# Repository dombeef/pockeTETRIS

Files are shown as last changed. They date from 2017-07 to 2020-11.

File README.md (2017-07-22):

# pockeTETRIS
This project originally was meant as a fathers day gift for my tetris-loving father, and I felt like it should be available for others if they want to make a pretty small tetris clone. This was the smallest I could make it with a big enough battery and a thick durable 3d printed housing.

I modified tetris code created by Andy Jackson to be used with 3 buttons, since his original code was made for the AttinyArcade platform that has 2 buttons.

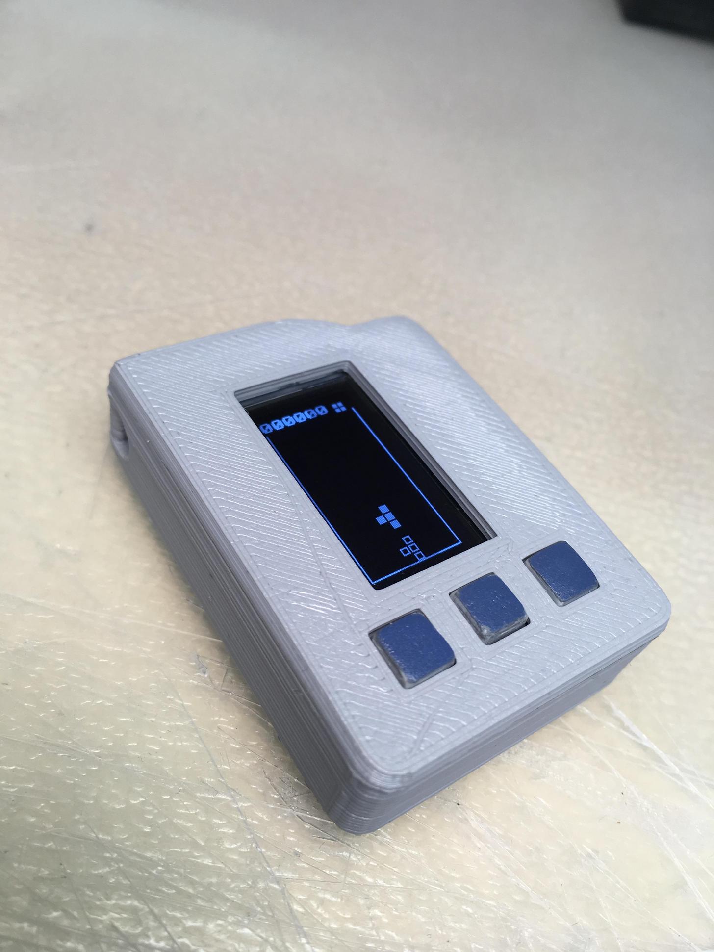
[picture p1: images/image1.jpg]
Final product


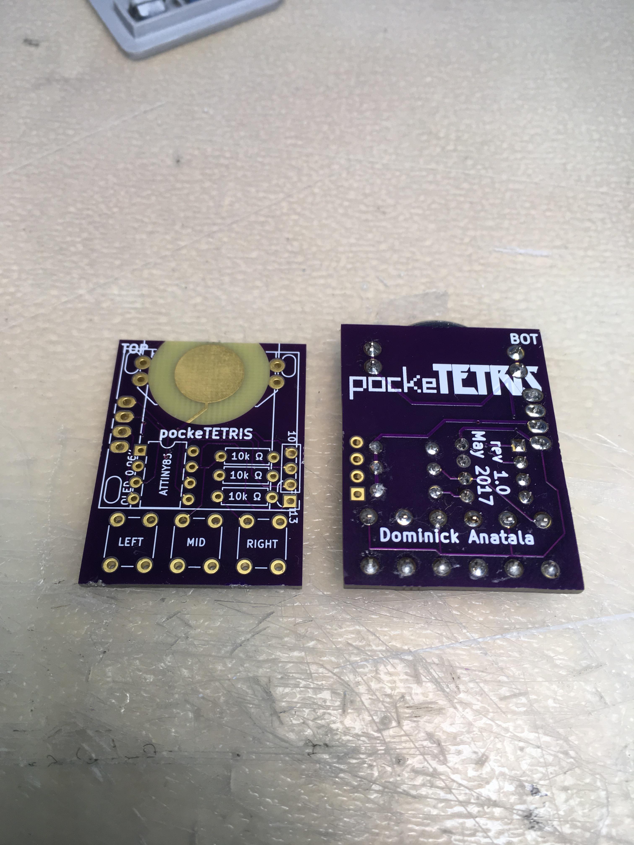
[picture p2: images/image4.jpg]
hand designed PCB with custom logo


### BOM
| Part  | Part number/ place to buy|
| --- | --- |
| Attiny85 | ATTINY85-20PU |
| CR2032 | CR2032 |
| Coin cell holder | BAT-HLD-001-THM|
| PCB from OSH Park | https://oshpark.com/shared_projects/mLy9Mwcr |
| 3d printed case | STL's available in the catia subfolder |
| buttons | [6x6x5 mm Push Button](https://www.amazon.com/CO-RODE-Tact-Button-Switch-6x6x5mm/dp/B00W0YUV1W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) |
| OLED 0.96' | [DIYmall 0.96" OLED](https://www.amazon.com/Diymall-Serial-128x64-Display-Arduino/dp/B01HHOETIA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) |
| 10 k Resistors | 1/4 Watt 10k ohm Resistors |

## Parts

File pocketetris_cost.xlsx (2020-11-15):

items | quantity | quantity needed | cost total | cost per unit | units possible | extra
Attiny85 | 5 | 1 | 10.98 | 2.196 | 5 | https://www.amazon.com/Original-Atmel-Dip-8-ATTINY85-20PU-Tiny85-20Pu/dp/B06W9JBJJ6?s=industrial
CR2032 | 4 | 1 | 2.68 | 0.67 | 4 | https://www.amazon.com/Energizer-2032BP-4-Volt-Lithium-Battery/dp/B00D8P5T0U?s=hpc
Coin cell holder | 10 | 1 | 2.8 | 0.28 | 10
pcb | 3 | 1 | 8.95 | 2.983333333 | 3
3d printed case | 1 | 1 | 0 | 0 | 1
buttons | 100 | 3 | 6.8 | 0.068 | 33.33333333 | https://www.amazon.com/CO-RODE-Tact-Button-Switch-6x6x5mm/dp/B00W0YUV1W
OLED 0.96' | 2 | 1 | 14.99 | 7.495 | 2 | https://www.amazon.com/Diymall-Serial-128x64-Display-Arduino/dp/B01HHOETIA
Resistors | 3 | 3 | 0 | 0 | 1
 |  | Total: | 47.2 | 13.69233333
through better bulk stuff
items | quantity | quantity needed | cost total | cost per unit | units possible
Attiny85 | 1 | 1 | 1.2 | 1.2 | 1 | https://www.digikey.com/en/products/detail/microchip-technology/ATTINY85-20PU/735469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
CR2032 | 1 | 1 | 0.33 | 0.33 | 1 | https://www.digikey.com/en/products/detail/zeus-battery-products/CR2032/9828855
Coin cell holder | 500 | 1 | 60 | 0.12 | 500 | https://www.alibaba.com/product-detail/Coin-Cell-Retainer-CR2032-2032-2020_62430101585.html
pcb | 10 | 1 | 5 | 0.5 | 10 | pcbway
3d printed case | 1 | 1 | 0 | 0 | 1
buttons | 20 | 1 | 0.5 | 0.025 | 20
OLED 0.96' | 10 | 1 | 18.6 | 1.86 | 10 | https://www.aliexpress.com/item/32717542815.html
Resistors | 3 | 3 | 0 | 0 | 1
 |  | Total: | 85.63 | 4.035

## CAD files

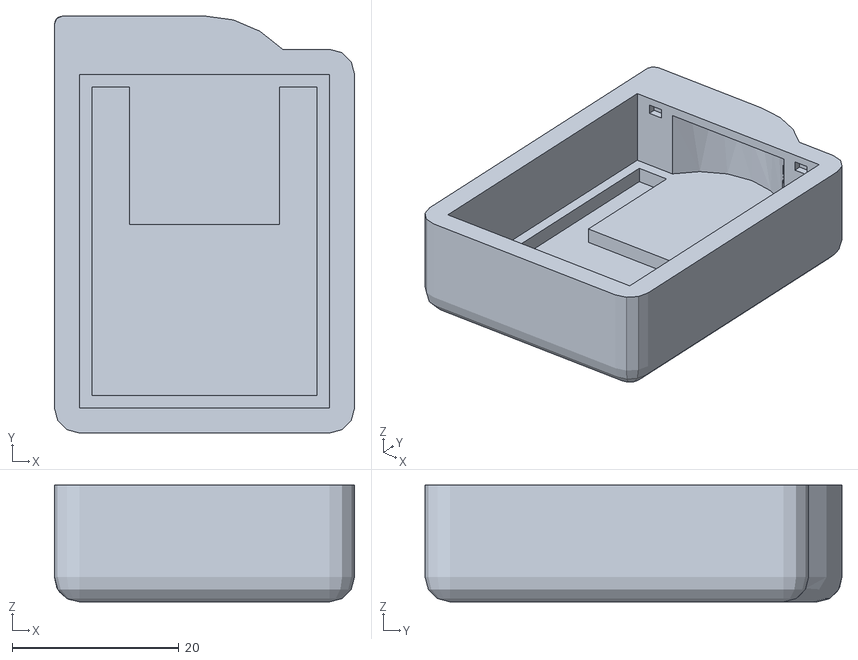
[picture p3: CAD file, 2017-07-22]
pockeTETRIS_catia/tetris_case_bottom.stl
36.0 x 50.0 x 14.0

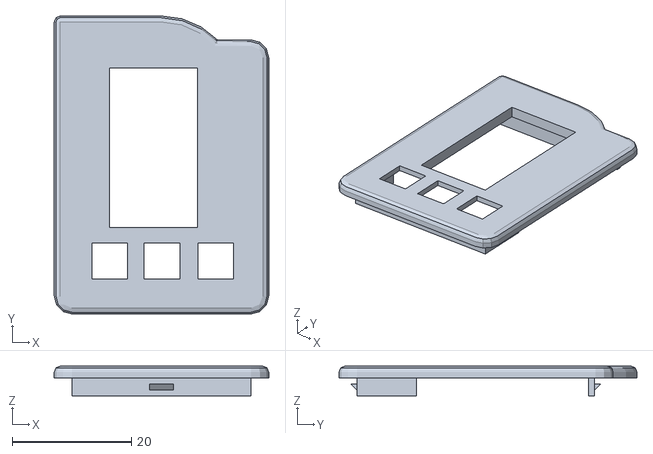
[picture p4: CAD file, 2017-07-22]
pockeTETRIS_catia/tetris_case_top.stl
36.0 x 50.0 x 5.00

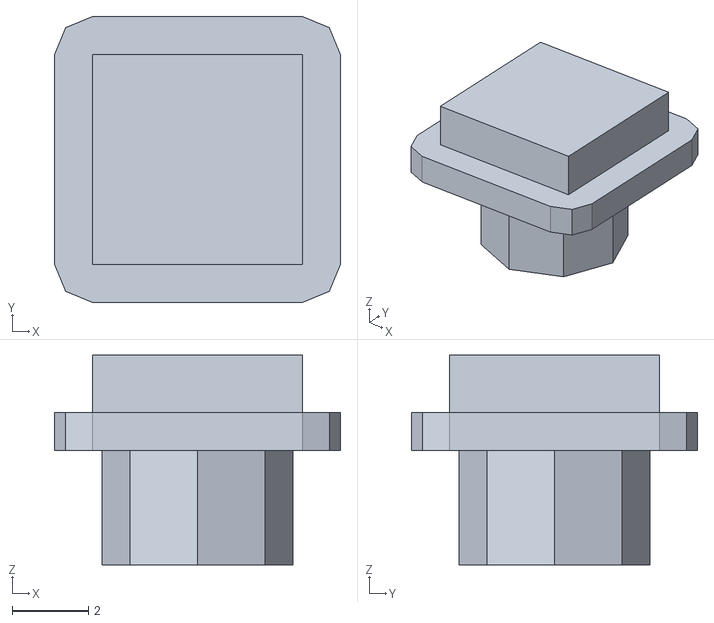
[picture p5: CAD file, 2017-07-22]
pockeTETRIS_catia/tetris_case_button_flush.stl
7.50 x 7.50 x 5.50

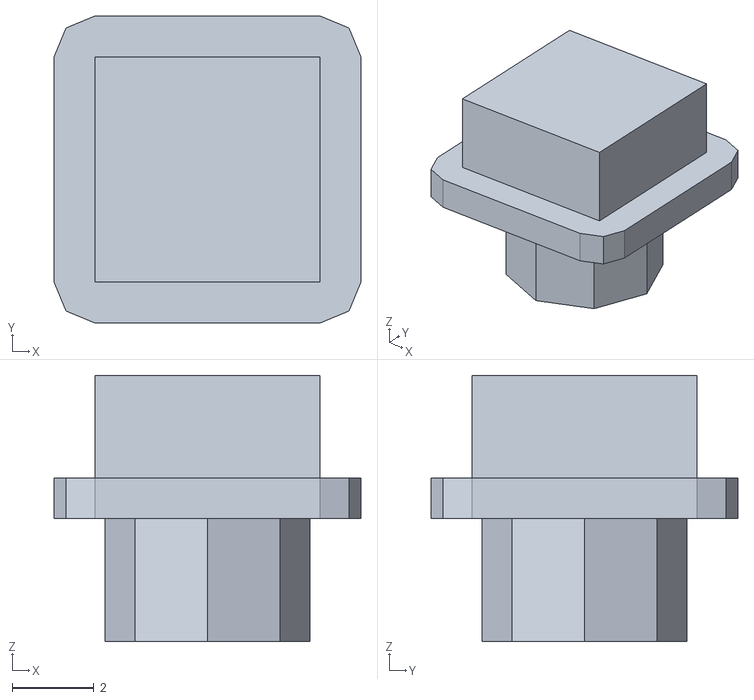
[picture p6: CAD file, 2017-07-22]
pockeTETRIS_catia/tetris_case_button.stl
7.50 x 7.50 x 6.50

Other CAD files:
pockeTETRIS_catia/tetris_assembly.CATProduct
pockeTETRIS_catia/tetris_case_bottom.CATPart
pockeTETRIS_catia/tetris_case_button.CATPart
pockeTETRIS_catia/tetris_case_button_flush.CATPart
pockeTETRIS_catia/tetris_case_top.CATPart

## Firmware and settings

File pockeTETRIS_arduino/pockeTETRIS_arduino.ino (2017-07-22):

/* 2015 / 2016 /2017

    Dominick Anatala
    modified for 3 buttons, removed wrapping around edges since we now have 3 buttons
        

   Tetris for Attiny Arcade
   ========================

   When the game is running :
   ==========================
   
   Tap LEFT BUTTON - Moves the piece to the left (and wraps around at the left edge)
   Hold LEFT BUTTON - Move the piece to the right
   Tap RIGHT BUTTON - Rotates the piece
   Hold RIGHT BUTTON - Place the piece

   Before the game starts:
   =======================
   Hold LEFT BUTTON - Turns 'ghost' piece on and off
   Hold MIDDLE and LEFT BUTTONS together - Turns 'challenge mode' on and off (which fills the screens with random stuff at the start of the game to make
   it more tricky!)


   _______________________________________________
   __________________________________________________________________________________________________________
   This version developed by Andy Jackson - Twitter @andyhighnumber - Tweet me if you have any problems getting this to compile or run.
   The code that does not fall under
   the licenses of sources listed below can be used non-commercially with or without attribution.
   This software is supplied without warranty of any kind.

   Designed for the Attiny85 and optimised for the #AttinyArcade platform. The source code is less than 8KB and the sketch
   should run happily with less than 300 bytes of RAM. You can find out more about this platform from http://webboggles.com/, buy kits
   to make it (or get instructions / schematics). This sketch includes some code from the #AttinyArcade games on that site, including interrupt code.

   This game started life as a port but is now essentially a clone of TinyTetris by Anthony Russell, with some additional features. There remain
   elements of that original codebase, although the vast majority of what's here has been rewritten from scratch (including the screen, text and number
   rendering code and much of the game engine) in order to optimise for memory, improve responsiveness and allow new features on the limited hardware
   (added features include Highscore (saved to EEPROM), optional Ghost (or Shadow) Piece, Interrupt Handling and Hard-Mode functionality).

   Anthony's source can be found here: https://github.com/AJRussell/Tiny-Tetris and is highly recommended if you'd like a version
   of Tetris to run on normal Arduino hardware. It has some lovely graphics by Tobozo (one image from which is now inclded the opening screen here!) and it's
   also possible that some code by Tobozo has made it into this version. Tobozo's repository can be found here; https://github.com/tobozo and is well worth a look.
   There is an In]]]
   structables page relating to this project here: https://www.instructables.com/id/Tetris-Clone-With-OLED-SSD1306I2C-for-Arduino-Nano/

   This sketch is using the screen control and font functions written by Neven Boyanov for the http://tinusaur.wordpress.com/ project
   Source code and font files available at: https://bitbucket.org/tinusaur/ssd1306xled - hacked about by Andy Jackson to make them
   render side-on for this game. All the necessary functions are in this file, there's no need to download any additional libraries to compile this game.

   The sleep code in this file is based on this blog post by Matthew Little:
   http://www.re-innovation.co.uk/web12/index.php/en/blog-75/306-sleep-modes-on-attiny85
*/

// The custom font file is the only additional file you should need to compile this game
#include "font8x8AJ.h"

// Standard Arduino headers
#include <EEPROM.h>
#include <avr/pgmspace.h>
#include <avr/sleep.h>
#include <avr/interrupt.h> // needed for the additional interrupt

// Mode settings for functions with multiple purposes
#define NORMAL 0
#define GHOST 1
#define FULL 0
#define PARTIAL 1
#define DRAW 0
#define ERASE 1

// The horizontal width of the playing area
#define HORIZ 10
// The vertical visible space of the playing area
#define VERTDRAW 19
// The size of the array of blocks (some are outside visible area to allow them to drop in from off screen)
#define VERTMAX 24

// The horizontal position where pieces begin
#define STARTX 3
// The vertical position where pieces begin
#define STARTY 19
// What level does the game start on
#define STARTLEVEL 1
// The multiplying factor that sets how the speed scales with level (one level increment for every row cleared)
#define LEVELFACTOR 4
// The number of milliseconds before each drop (baseline)
#define DROPDELAY 600

#define DIGITAL_WRITE_HIGH(PORT) PORTB |= (1 << PORT)
#define DIGITAL_WRITE_LOW(PORT) PORTB &= ~(1 << PORT)

// Routines to set and clear bits (used in the sleep code)
#define cbi(sfr, bit) (_SFR_BYTE(sfr) &= ~_BV(bit))
#define sbi(sfr, bit) (_SFR_BYTE(sfr) |= _BV(bit))

// Defines for OLED output
#define SSD1306XLED_H
#define SSD1306_SCL   PORTB4  // SCL, Pin 4 on SSD1306 Board - for webbogles board
#define SSD1306_SDA   PORTB3  // SDA, Pin 3 on SSD1306 Board - for webbogles board
#define SSD1306_SA    0x78  // Slave address

// The bitmaps for the little images of next block
static const byte miniBlock[][4] PROGMEM = {
  {0x77, 0x77, 0x00, 0x00},
  {0x70, 0x77, 0x70, 0x00},
  {0x70, 0x00, 0x70, 0x77},
  {0x70, 0x07, 0x70, 0x07},
  {0x70, 0x07, 0x00, 0xEE},
  {0x70, 0x77, 0x00, 0x0E},
  {0x70, 0x07, 0xEE, 0x00}
};

// The bitmaps for the main blocks
static const int blocks[7] PROGMEM = {
  0x4444, 0x44C0,
  0x4460, 0x0660,
  0x06C0, 0x0E40,
  0x0C60
};

// The bitmaps for blocks on the screen
static const byte  blockout[16] PROGMEM = {
  0xF8, 0x00, 0x3E, 0x80,
  0x0F, 0xE0, 0x03, 0xF8,
  0x3E, 0x80, 0x0F, 0xE0,
  0x03, 0xF8, 0x3E, 0x00
};

// The bitmaps for ghost blocks on the screen
static const byte  ghostout[16] PROGMEM = {
  0x88, 0x00, 0x22, 0x80,
  0x08, 0x20, 0x02, 0x88,
  0x22, 0x80, 0x08, 0x20,
  0x02, 0x88, 0x22, 0x00
};

// Decode lookup to translate block positions to the 8 columns on the screen
static const byte startDecode[11] PROGMEM = {0, 1, 1, 2, 3, 4, 4, 5, 6, 7, 8};
static const byte endDecode[11] PROGMEM =   {1, 2, 3, 3, 4, 5, 6, 6, 7, 8, 8};

// The  logo on the opening screen - adapted from the original by Tobozo https://github.com/tobozo

const byte brickLogo[] PROGMEM = {
  0x01, 0x01, 0x01, 0x01, 0x81, 0x81, 0xC1, 0xE1,
  0xF1, 0xF1, 0x01, 0x11, 0xF1, 0xF1, 0xE1, 0xC1,
  0xC1, 0x81, 0x81, 0x01, 0x01, 0x01, 0x01, 0x01,
  0x01, 0x01, 0x01, 0x01, 0x01, 0x01, 0x01, 0x01,
  0x01, 0x01, 0x01, 0x01, 0xFC, 0xFC, 0xFE, 0xFF,
  0xFF, 0xFF, 0xFF, 0xFF, 0xFF, 0xFF, 0xFF, 0x00,
  0xFF, 0xFF, 0xFF, 0xFF, 0xFF, 0xFF, 0xFF, 0xFF,
  0xFF, 0xFE, 0xF8, 0x00, 0x00, 0x00, 0x00, 0x00,
  0x00, 0x00, 0x00, 0x00, 0x00, 0x00, 0x00, 0x00,
  0xFF, 0xFF, 0x7F, 0x3F, 0xBF, 0x9F, 0xCF, 0xEF,
  0xE7, 0xF7, 0xFB, 0xE0, 0x01, 0xFB, 0xF3, 0xF7,
  0xE7, 0xEF, 0xCF, 0xDF, 0xDF, 0xBF, 0xBF, 0x30,
  0x00, 0x00, 0x00, 0x00, 0x00, 0x00, 0x00, 0x00,
  0x00, 0x00, 0x00, 0x00, 0x00, 0xFE, 0xFF, 0xFF,
  0xFF, 0xFF, 0xFF, 0xFF, 0xFF, 0xFF, 0xFF, 0xFF,
  0x00, 0x3F, 0xFF, 0xFF, 0xFF, 0xFF, 0xFF, 0xFF,
  0xFF, 0xFF, 0xFF, 0xFF, 0xE0, 0x06, 0xFE, 0xFC,
  0xFC, 0xFC, 0xF8, 0xF8, 0xF0, 0xF0, 0xE0, 0x00,
  0x00, 0xFF, 0xFF, 0x7F, 0x7F, 0x3F, 0xBF, 0x9F,
  0xDF, 0xCF, 0xEF, 0xEF, 0xE4, 0x00, 0xF7, 0xE7,
  0xEF, 0xEF, 0xCF, 0xDF, 0xDF, 0x9F, 0xBF, 0xBF,
  0x3F, 0x00, 0x07, 0x7F, 0xFF, 0xFF, 0xFF, 0xFF,
  0xFF, 0xFF, 0xFF, 0xF0, 0x00, 0xFC, 0xFE, 0xFE,
  0xFF, 0xFF, 0xFF, 0xFF, 0xFF, 0xFF, 0xFF, 0xFF,
  0xFF, 0x80, 0x07, 0xFF, 0xFF, 0xFF, 0xFF, 0xFF,
  0xFF, 0xFF, 0xFF, 0xFF, 0xFF, 0xFF, 0xC0, 0x0E,
  0x3E, 0x1E, 0x1C, 0x1D, 0x0D, 0x09, 0x03, 0x03,
  0x00, 0x07, 0xFF, 0xFF, 0xFF, 0xFF, 0xFF, 0xFF,
  0xFF, 0xFF, 0xFF, 0x7F, 0x7F, 0x3F, 0x00, 0x3F,
  0x3F, 0x7F, 0x7F, 0x7F, 0x7F, 0x7F, 0xFF, 0xFF,
  0xFF, 0xFF, 0xFF, 0x80, 0x00, 0x00, 0x00, 0x00,
  0x00, 0x00, 0x00, 0x00, 0x80, 0x80, 0x83, 0x83,
  0x83, 0x89, 0x8D, 0x8D, 0x8C, 0x8E, 0x8E, 0x8E,
  0x8F, 0x8F, 0x9F, 0x8F, 0x8F, 0x8F, 0x8F, 0x87,
  0x86, 0x86, 0x82, 0x82, 0x82, 0x80, 0x80, 0x80,
  0x80, 0x80, 0x80, 0x80, 0x80, 0x80, 0x80, 0x80
};


// Function prototypes - generic ones I use in all games
void doNumber (int x, int y, int value);

// Function prototypes - screen control modified from https://bitbucket.org/tinusaur/ssd1306xled
void ssd1306_init(void);
void ssd1306_xfer_start(void);
void ssd1306_xfer_stop(void);
void ssd1306_send_byte(uint8_t byte);
void ssd1306_send_command(uint8_t command);
void ssd1306_send_data_start(void);
void ssd1306_send_data_stop(void);
void ssd1306_setpos(uint8_t x, uint8_t y);
void ssd1306_fillscreen(uint8_t fill_Data);
void ssd1306_char_f8x8(uint8_t x, uint8_t y, const char ch[]);

// Function prototypes - tetris-specific
void playTetris(void);
void handleInput(void);

void drawScreen(int startCol, int endCol, int startRow, int endRow, byte mode);
void drawScreenBorder(void);

byte readBlockArray(byte x, byte y);
void writeblockArray(byte x, byte y, bool value);
byte readGhostArray(byte x, byte y);
void writeGhostArray(byte x, byte y, bool value);
void fillGrid(byte value, bool mode);

void rotatePiece(void);
bool movePieceDown(void);
void movePieceLeft(void);
void movePieceRight(void);
byte checkCollision(void);

bool createGhost(void);
void drawGhost(byte action);
void loadPiece(byte pieceNumber, byte row, byte column);
void drawPiece(byte action);
void setNextBlock(byte pieceNumber);

// Variables
struct pieceSpace {
  byte blocks[4][4];
  int row;
  int column;
};

pieceSpace currentPiece = {0};  // The piece in play
pieceSpace oldPiece = {0};      // Buffer to hold the current piece whilst its manipulated
pieceSpace ghostPiece = {0};    // Current ghost piece

unsigned long moveTime = 0;     // Baseline time for current move
unsigned long keyTime = 0;      // Baseline time for current keypress

byte keyLock = 0;               // Holds the mode of the last keypress (for debounce and stuff)

byte nextBlockBuffer[8][2];     // The little image of the next block
byte nextPiece = 0;             // The identity of the next piece
byte blockArray[HORIZ][3];      // The byte-array of blocks
byte ghostArray[HORIZ][3];      // The byte-array of ghost pieces
bool stopAnimate;               // True when the game is running

int lastGhostRow = 0;           // Buffer to hold previous ghost position - for accurate drawing
int score = 0;                  // Score buffer
int topScore = 0;               // High score buffer

bool challengeMode = 0;         // Is the system in "Hard" mode?
bool ghost = 1;                 // Is the ghost active?

int level = 0;                  // Current level (increments once per cleared line)

void doNumber (int x, int y, int value) {
  char temp[10] = {0, 0, 0, 0, 0, 0, 0, 0, 0, 0};
  itoa(value, temp, 10);
  ssd1306_char_f8x8(x, y, temp);
}


void ssd1306_char_f8x8(uint8_t x, uint8_t y, const char ch[]) {
  uint8_t c, i, j = 0;

  while (ch[j] != '\0')
  {
    c = ch[j] - 32; // to space
    if (c > 0) c = c - 12; // to dash
    if (c > 15) c = c - 7;
    if (c > 40) c = c - 6;

    ssd1306_setpos(y, x);
    ssd1306_send_data_start();
    for (byte lxn = 0; lxn < 8; lxn++) {
      ssd1306_send_byte(pgm_read_byte(&font[c][7 - lxn]));
    }
    ssd1306_send_data_stop();
    x += 1;
    j++;
  }
}

// Interrupt handlers - to make sure every button press is caught promptly!
ISR(PCINT0_vect) { // PB0 pin button interrupt
  if (keyLock == 0) {
    keyLock = 1;
    keyTime = millis();
  }
  if (digitalRead(1) == HIGH){
    keyLock = 3;
  }
}

void playerIncTetris() { // PB2 pin button interrupt
  if (keyLock == 0) {
    keyLock = 2;
    keyTime = millis();
  }
}

//added for 3rd button
void playerIncTetris1() { // PB1 pin button interrupt
  if (keyLock == 0) {
    keyLock = 3;
    keyTime = millis();
  }
}

// Screen control functions
void ssd1306_init(void) {
  DDRB |= (1 << SSD1306_SDA); // Set port as output
  DDRB |= (1 << SSD1306_SCL); // Set port as output

  ssd1306_send_command(0xAE); // display off
  ssd1306_send_command(0x00); // Set Memory Addressing Mode
  ssd1306_send_command(0x10); // 00,Horizontal Addressing Mode;01,VERTDRAWical Addressing Mode;10,Page Addressing Mode (RESET);11,Invalid
  ssd1306_send_command(0x40); // Set Page Start Address for Page Addressing Mode,0-7
  ssd1306_send_command(0x81); // Set COM Output Scan Direction
  ssd1306_send_command(0xCF); // ---set low column address
  ssd1306_send_command(0xA1); // ---set high column address
  ssd1306_send_command(0xC8); // --set start line address
  ssd1306_send_command(0xA6); // --set contrast control register
  ssd1306_send_command(0xA8);
  ssd1306_send_command(0x3F); // --set segment re-map 0 to 127
  ssd1306_send_command(0xD3); // --set normal display
  ssd1306_send_command(0x00); // --set multiplex ratio(1 to 64)
  ssd1306_send_command(0xD5); //
  ssd1306_send_command(0x80); // 0xa4,Output follows RAM content;0xa5,Output ignores RAM content
  ssd1306_send_command(0xD9); // -set display offset
  ssd1306_send_command(0xF1); // -not offset
  ssd1306_send_command(0xDA); // --set display clock divide ratio/oscillator frequency
  ssd1306_send_command(0x12); // --set divide ratio
  ssd1306_send_command(0xDB); // --set pre-charge period
  ssd1306_send_command(0x40); //
  ssd1306_send_command(0x20); // --set com pins hardware configuration
  ssd1306_send_command(0x02);
  ssd1306_send_command(0x8D); // --set vcomh
  ssd1306_send_command(0x14); // 0x20,0.77xVcc
  ssd1306_send_command(0xA4); // --set DC-DC enable
  ssd1306_send_command(0xA6); //
  ssd1306_send_command(0xAF); // --turn on oled panel
}

void ssd1306_xfer_start(void) {
  DIGITAL_WRITE_HIGH(SSD1306_SCL);  // Set to HIGH
  DIGITAL_WRITE_HIGH(SSD1306_SDA);  // Set to HIGH
  DIGITAL_WRITE_LOW(SSD1306_SDA);   // Set to LOW
  DIGITAL_WRITE_LOW(SSD1306_SCL);   // Set to LOW
}

void ssd1306_xfer_stop(void) {
  DIGITAL_WRITE_LOW(SSD1306_SCL);   // Set to LOW
  DIGITAL_WRITE_LOW(SSD1306_SDA);   // Set to LOW
  DIGITAL_WRITE_HIGH(SSD1306_SCL);  // Set to HIGH
  DIGITAL_WRITE_HIGH(SSD1306_SDA);  // Set to HIGH
}
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
void loop() {
  ssd1306_init();
  ssd1306_fillscreen(0x00);

  ssd1306_char_f8x8(1, 64, "TETRIS");
  /* The lowercase character set is seriously compromised and hacked about to remove unused letters in order to save code space
     .. hence all lowercase words look like nonsense! See font8x8AJ.h for details on the mapping.
  */
  
  ssd1306_char_f8x8(1, 48, " FOR");
  ssd1306_char_f8x8(1, 40, "DADDIO");

  drawScreenBorder();

  for (byte lxn = 0; lxn < 8; lxn++) {
    ssd1306_setpos(78, lxn);
    ssd1306_send_data_start();
    for (byte lxn2 = 0; lxn2 < 36; lxn2++) {
      ssd1306_send_byte(pgm_read_byte(&brickLogo[36 * lxn + lxn2]));
    }
    ssd1306_send_data_stop();
  }

  long startT = millis();
  long nowT = 0;
  boolean sChange = 0;
  while (digitalRead(0) == HIGH) {
    nowT = millis();
    if (nowT - startT > 2000) {
      sChange = 1;
      if (digitalRead(2) == HIGH) {
        ssd1306_char_f8x8(2, 8, "MODE");
        if (challengeMode == 0) {
          challengeMode = 1;
          ssd1306_char_f8x8(2, 16, "HARD");
        } else {
          challengeMode = 0;
          ssd1306_char_f8x8(1, 16, "NORMAL");
        }
      } else {
        ssd1306_char_f8x8(1, 16, "GHOST");
        if (ghost == 0) {
          ghost = 1;
          ssd1306_char_f8x8(2, 8, "ON");
        } else {
          ghost = 0;
          ssd1306_char_f8x8(2, 8, "OFF");
        }
      }
      break;
    }
    if (sChange == 1) break;
  }
  while (digitalRead(0) == HIGH);

  if (sChange == 0) {
    delay(1600);

    ssd1306_char_f8x8(1, 20, "LOVE");
    ssd1306_char_f8x8(1, 10, "DOM");
    delay(1500);
    ssd1306_fillscreen(0x00);
    playTetris();
  }
  delay(1000);
  system_sleep();
}

byte readBlockArray(byte x, byte y) {
  if (y < 8) {
    return ((blockArray[x][0] & B00000001 << y) >> y);
  } else if (y > 15) {
    return ((blockArray[x][2] & B00000001 << y - 15) >> y - 15);
  } else {
    return ((blockArray[x][1] & B00000001 << y - 8) >> y - 8);
  }
}

void writeblockArray(byte x, byte y, bool value) {
  byte arr = 0;
  if (y < 8) {
    // do nothing
  } else if (y > 15) {
    arr = 2;
    y -= 15;
  } else  {
    arr = 1;
    y -= 8;
  }
  if (value == 1) blockArray[x][arr] |= B00000001 << y; else blockArray[x][arr] &= (B11111110 << y) | (B01111111 >> 7 - y);
}

byte readGhostArray(byte x, byte y) {
  if (y < 8) {
    return ((ghostArray[x][0] & B00000001 << y) >> y);
  } else if (y > 15) {
    return ((ghostArray[x][2] & B00000001 << y - 15) >> y - 15);
  } else {
    return ((ghostArray[x][1] & B00000001 << y - 8) >> y - 8);
  }
}

void writeGhostArray(byte x, byte y, bool value) {
  byte arr = 0;
  if (y < 8) {
    // do nothing
  } else if (y > 15) {
    arr = 2;
    y -= 15;
  } else  {
    arr = 1;
    y -= 8;
  }
  if (value == 1) ghostArray[x][arr] |= B00000001 << y; else ghostArray[x][arr] &= (B11111110 << y) | (B01111111 >> 7 - y);
}

void fillGrid(byte value, bool mode) {
  for (char r = 0; r < VERTMAX; r++) {
    for (char c = 0; c < HORIZ; c++) {
      if (mode == GHOST) writeGhostArray(c, r, value); else writeblockArray(c, r, value);
    }
  }
}

void rotatePiece(void) {
  byte blocks[4][4];

  memcpy(oldPiece.blocks, currentPiece.blocks, 16);
  oldPiece.row = currentPiece.row;
  oldPiece.column = currentPiece.column;

  for (byte i = 0; i < 4; ++i) {
    for (byte j = 0; j < 4; ++j) {
      blocks[j][i] = currentPiece.blocks[4 - i - 1][j];
    }
  }
  oldPiece = currentPiece;
  memcpy(currentPiece.blocks, blocks, 16);
  if (checkCollision()) currentPiece = oldPiece; else {
    drawGhost(ERASE);
    if (createGhost()) drawGhost(DRAW);
  }
}

bool movePieceDown(void) {
  int rndPiece = 0;

  memcpy(oldPiece.blocks, currentPiece.blocks, 16);
  oldPiece.row = currentPiece.row;
  oldPiece.column = currentPiece.column;

  currentPiece.row--;

  //check collision
  if (checkCollision()) {
    currentPiece.row = oldPiece.row;
    drawPiece(DRAW);
    byte totalRows = 0;

    for (byte row = 0; row < VERTMAX; row++) { // scan the whole block (it's quick - there's no drawing to do)
      bool rowFull = 1;
      for (byte col = 0; col < HORIZ; col++) { // scan across this row - every column
        if (readBlockArray(col, row) == 0) rowFull = 0; // if we hit any blank spaces, the row's not full
      }
      if (rowFull) {
        totalRows++;
        for (byte col = 0; col < HORIZ; col++) writeblockArray(col, row, 0); // write zeros across this whole row
        drawGameScreen(0, HORIZ - 1, row, row + 1, PARTIAL); // draw the row we're removing (for animation)
        delay(30); // delay slightly to make the deletion of rows visible
        for (byte dropCol = 0; dropCol < HORIZ; dropCol++) { // for every column
          for (byte dropRow = row; dropRow < VERTMAX - 1; dropRow ++) writeblockArray(dropCol, dropRow, readBlockArray(dropCol, dropRow + 1)); // drop everything down as many as the row's we've cleared
        }
        row--; // we need to check this row again as it could now have things in it!
      }
    }
    level += totalRows;
    switch (totalRows) {
      case 1:   score += 40; break;
      case 2:   score += 100; break;
      case 3:   score += 300; break;
      case 4:   score += 800;
    }
    drawGameScreen(0, 10, 0, VERTDRAW, FULL);
    displayScore(score, 0, 117, 0);
    loadPiece(nextPiece, STARTY, STARTX);
    if (checkCollision()) {
      stopAnimate = true;
    } else {
      loadPiece(nextPiece, STARTY, STARTX);
      drawGhost(ERASE);
      if (createGhost()) drawGhost(DRAW);
    }
    nextPiece = random(1, 8);
    setNextBlock(nextPiece);
  }
  drawGhost(ERASE);
  if (createGhost()) drawGhost(DRAW);
}

/* remove wrapping around edges
  void movePieceLeft(void) {
  byte response;

  oldPiece = currentPiece;
  currentPiece.column = currentPiece.column - 1;

  response = checkCollision();

  if (response == 1) {
    currentPiece = oldPiece; // back to where it was
  } else if (response == 2) {
    int wide = 0;
    for (byte i = 0; i < 4; i++) {
      if (currentPiece.blocks[3][i]) wide = 1;
    }
    boolean narrow = true;
    for (byte i = 0; i < 4; i++) {
      if (currentPiece.blocks[2][i]) narrow = false;
    }
    if (narrow) wide = -1;
    currentPiece.column = 7 - wide;
    response = checkCollision(); // Check again - does wrapping around cause a collision?
    if (response == 1) {
      currentPiece = oldPiece; // back to where it was
    } else {
      drawGhost(ERASE);
      if (createGhost()) drawGhost(DRAW);
      drawGameScreen(0, 10, 0, VERTDRAW, FULL);
    }
  } else {
    drawGhost(ERASE);
    if (createGhost()) drawGhost(DRAW);
  }
  }
*/

void movePieceLeft(void) {
  oldPiece = currentPiece;
  currentPiece.column = currentPiece.column - 1;
  //check collision
  if (checkCollision())   {
    currentPiece = oldPiece; // back to where it was
  } else {
    drawGhost(ERASE);
    if (createGhost()) drawGhost(DRAW);
  }
}

void movePieceRight(void) {
  oldPiece = currentPiece;
  currentPiece.column = currentPiece.column + 1;
  //check collision
  if (checkCollision()) 	{
    currentPiece = oldPiece; // back to where it was
  } else {
    drawGhost(ERASE);
    if (createGhost()) drawGhost(DRAW);
  }
}

byte checkCollision(void) {
  byte pieceRow = 0;
  byte pieceColumn = 0;

  for (int c = currentPiece.column; c < currentPiece.column + 4; c++) {
    for (int r = currentPiece.row; r < currentPiece.row + 4; r++) {
      if (currentPiece.blocks[pieceColumn][pieceRow]) {
        if (c < 0) return 2;
        if (c > 9) return 1;
        if (r < 0) return 1;
        if (c >= 0 && r >= 0 && c < HORIZ && r < VERTMAX) {
          if (readBlockArray(c, r)) {
            return 1; //is it on landed blocks?
          }
        }
      }
      pieceRow++;
    }
    pieceRow = 0;
    pieceColumn++;
  }
  return 0;
}
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

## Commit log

2017-07-22 First upload
    [pocketetris_cost.xlsx, tetris_assembly.CATProduct, tetris_case_bottom.CATPart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]
2017-08-13 Added schematic
    [tinytetris.sch]
2020-11-15 updated bom
    working towards cheaper bom
    [pocketetris_cost.xlsx]
